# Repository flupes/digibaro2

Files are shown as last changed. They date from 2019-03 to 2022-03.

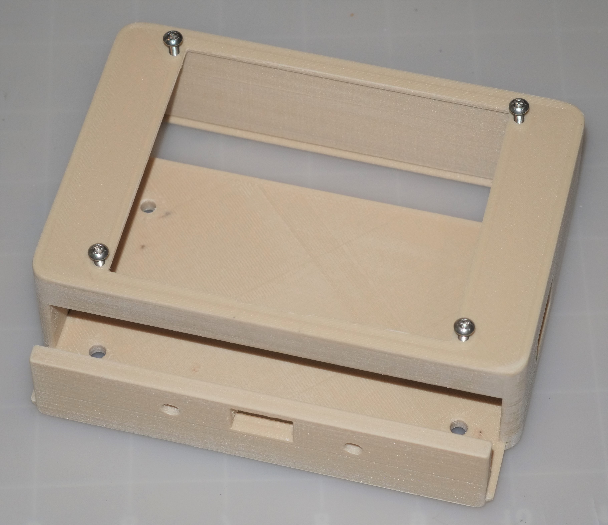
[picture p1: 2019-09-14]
brochure/D_mechanical/D4_enclosure.jpg

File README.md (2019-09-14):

# Digital Barograph v2 (with e-Paper display).

Status:
- all supporting custom libraries are now written and include tests
- main application functional
- schematic for board produced (one hole need fix)
- 3D [enclosure design with wooden plate](https://a360.co/2I1p0DZ) completed

Digibaro2 Photo

*Picture of the final barograph*

There is also a [complete user manual](./brochure/brochure.pdf) with a lot of cool
build pictures.
(The brochure has been written in French because I offered a Digibaro to
my father for his 80th birthday, but it should not prevent you to have a look
at it!)

## Goal

Develop an open source digital barograph that does not require an external power
source, has a very low power consumption, and works on a boat independantly of
any wifi/cell connection.

## Motivation

I still believe that the barometric pressure is an essential decision making
tool when sailing. Displaying a graph rather than writing down single values
provides an instant evaluation of the trend.

The main idea is that the beautifull conventional mechanical barograph are not
suited for marine use (not resistant to vibration) and require a weekly paper
change.

Classical Barograph

The paper-electronic barographs aleviate this problem, but I remember that ours
was constantly jamming.

Several electronic barograph already exist on the market, but they all require
an external source of power (and are pricey).

## Rationale

Today you can have an app that will siphon the data from a nearby weather
station and display the barometric pressure in any format using your brillant
smartphone screen. And this is even not really necessary since having data
connectivity would allow to also get a full detailed weather forecast, much more
accurate, and covering a wider area, than what you could analyze yourself.

Despite our ever more connected world, I am old fashioned and like to believe
that having systems not relying on data flowing wirelessly to your boat can be
useful. It turns out that the fundamental building block for such a project is
readily available: several extremely accurate digital pressure sensors can be
sourced at low price (you may already have one in your cellphone).

I also wanted not to rely on an external source of power. This is not so much to
avoid battery drain (the most basic solar panel would provide more than enough),
but to avoid having extra wiring.

The final concept is that you would be able to leave the barograph on your boat,
and when coming back after six months, you would be able to read the barometric
pressure of the last few days because the barograph would keep collecting data.
Of course, this is probably superfluous since after leaving your boat six
months, you probably have more than 5 days of work before taking the sea again
(hence you could turn on the barograph).

At any rate, being a style exercise or a real need, the goal is to develop an
extremly low power barograph that could sustain at least six months on a set of
typical AA alkaline batteries!

There are few major difference between this project an my previous (never
completed) digibaro v1:

| Digibaro v1 | Digibaro v2 |
|---|---|
| Target low cost | Cost is not the main priority |
| Classic UI with 5 buttons | Mimimalist UI (analog feel) |
| LCD screen | e-Paper display |
| Only stores 5 days of data  | Long term recording (>20years)|
| Typical "maker" approach | High reliability desired |

## Hardware selection

The [first version of my digibaro](https://github.com/flupes/digibaro/) was
based one BMP085 sensor, a momochrome graphic LCD and an Arduino Pro-Mini
(3.3V). This version use modernized components.

The micro-controller is a ARM Cortex M0+ (SAMD21) packaged by RocketScream. This
board was selected because it was specifically designed for low power
applications (no extra LEDs, efficient regulator, etc.), and it provides 2MB of
flash memory on board.

The pressure sensor is a BOSH BME280. It provides excellent accuracy plus a
humidity and temperature sensor on the chip. The BMP680 would provide an extra
Volatile Organic gas detector, but a the cost of an extra complexity in managing
the sensor.

The display is based on a 400x300 black and white e-Paper system packaged by
Waveshare. E-paper display would seem ideal for this type of low power
application. However, since the refresh rate is so slow (~4s for this particular
display), updating the display takes a significant amount energy. There is a
cutting-point between a LCD (that refresh very quickly and consume very low
power in standby) and an e-Paper display that depends on the number of refresh
per day. Still, for this application, the e-Paper provides a nice, more natural,
look.

## Reference products

[Bohlken BG1512](http://www.bohlken.net/bg/bg1512_en.htm)
- Require external power source
- 10mA without backlight
- Retired
- ~300 Euro

[Aquatech DBX2](https://www.digitalbarograph.com/)
- Require external power source
- 20mA @ 5V DC (160mA with LED backlight)
- Storm alarm
- Factory calibrated
- [DBX2 User Manual](https://www.digitalbarograph.com/pdfs/DBX2_MANUAL_V1W.pdf)  
- ~$500

[NASA Meteoman](https://www.nasamarine.com/product/meteoman/)
- Consumes 100mA (without backlight), require external source of power
- Pressure change graph
- [Meteoman screenshots and discussion](http://www.ybw.com/forums/showthread.php?452897-Calling-Weather-Experts-What-do-you-Need-in-a-Barograph)
- ~$200

[Raber Barograf](http://www.barograph.ch/Barograph_E/barograph.html)
- Paper recording :-)
- Swiss made ;-)
- One single C type battery for a year!
- Very cool, however we had a similar model that jammed quite often.  
- [Meteograf User Manual](http://www.barograph.ch/Downloads/BA_Meteograf_Englisch_2.4.pdf)  
- ~$900 without case

## Related projects

In May 2019, I just discovered this: [Arduino + BMP085 Barograph from PauloDevelo on Arbatus](https://www.arbutus.ecogium.fr/the-boat/electronic-equipment/barograph-arbutus/).

<!-- 
Code at: https://github.com/PauloDevelo/Barograph/blob/master/src/barograph.ino

This is similar to to what I started to develop with v1 of digibaro. However,
PauloDevelo chose a much simpler route: it is again powered from the boat
batteries (so not need for sleep mode), there is no RTC, no real concept of time
series, no user interface per say. This allowed him to complete the project
(unlike my digibaro v1). Congratulations! In addition, he created a nice wooden
enclosure.
-->

## Build

Currently digibaro2 is built using platformIO. This mainly constrains the
directory structure. Each test program show in the comments the command
to build it. The main application uses the platormio.ini definitions and
calls an extra script (version.py) to inject the git hash. This last part
is not directly portable to another build system.

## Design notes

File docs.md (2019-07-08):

## Platform

The code in this repo is specifically designed for an Arduino "zeroUSB"
compatible using a **ARM Cortex M0+**. The board used for my project is a
[Mini Ultra Pro v2](https://www.rocketscream.com/blog/docs-item/mini-ultra-pro-hookup-guide/)
from "Rocket Scream". The board was choosen because it has been designed for low
power application, and it already has a 2MB on-board flash. The Cortex M0 uses a
`SAMD21` which is a 32-bit microcontroller with 32KB or RAM. So there is very
little optimization to use types smaller than the native **word** `uint32_t` or
`int32_t`.

## Code organization

Most of the code resides in individuals libraries under `lib`. This allows for
much easier unit testing, at the cost of a lot of folders to deal with.

## General concepts

Class `BaroSample` holds information collected from the BME280 sensor, in a
slightly more compact form, using uint16_t rather than uint32_t. The class
also allows serialization and de-serialization to flash memory.

BaroSamples are written two flash using two classes:

  - `PermanentSamples` stores low frequency (typically hourly) samples, until
    the flash memory is full (~29 years of data!). These samples are not
    supposed to be deleted or written over.
  - `RotatingSamples` holds higher frequency samples (typically every 5
    minutes). This is a circular buffer, with samples being overwritten when the
    buffer is full. The length of this circular buffer ensure that the flash
    memory will not be subject to too many cycles.
    This class is supported by `RobustFlashIndexes` which maintains which is
    the last index of the circular buffer. The use of this separate circular
    buffer allows extra safety in maintaining the indexes because of the 
    redundancy and CRC offered by RobustFlashIndexes.

## Tests

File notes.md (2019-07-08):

Powershell tricks for the Linux guy
-----------------------------------

echo $PATH
$env:path -split ";"

which
(Get-Command cmd).Path

create new profile file
New-Item $profile -ItemType File -Force

test if path exist
Test-Path $profile

powershell editor
powershell_ise.exe $profile

create alias (only for session)
New-Item -Path Alias:python3 -Value C:\ProgramData\Anaconda3\python.exe

sloc count:
cloc --list-file=src-includes.lst --exclude-list-file=excluded.lst \
    --force-lang="C++",c --exclude-ext=csv

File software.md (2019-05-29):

# Digibaro Software Overview

All libraries used by digibaro2 are included with the repo, either as simple
directories (if the library is only relevant to digibaro), or as a git submodule
if the library has other application (this is the case for all the external
dependencies).

## Dependencies (External Libraries)

### Adafruit-GFX-Library

Used for all the drawing primitives and the canvas on which to draw.

### epd42

Waveshare code to drive their 4.2in black and white display. The drawing is done
on the Adafruit canvas, that is then pushed to the display.

### BME280_driver

This is the low level code provided by BOSH to interface with the BME280. Added
to this code is also a thin wrapper class to use the sensor Arduino style.

### FastCRC

Provides CRC functionalities

### RTCZero

SAMD21 internal RTC and power management.

### SPIMemory

Access the on-board flash.

## Internal Code and Libraries

### BaroUtils

Some utilities used by most of the code, like a printf dependent on the USB
avaibility.

### BaroSample
Management of data collected from the BME280 sensor (timestamp, serializing,
packing, etc.).

### PermanentSamples

Stores (and read) samples permanently in flash (just a linear succession of
samples).

### RobustFlashIndexes

Indexes on flash with redundancy and CRC checks.

### RotatingSamples

Rotating buffer on of sample on flash. Relies on RobustFlashIndexes.

### DisplaySamples

Creates RAM based timeseries of samples from flash.

### GraphSamples

Draw a graph from the DisplaySamples

### Labels

Compute nice axis label (from Numerical Recipes)

### RTClib

Manage the external DS3231 RTC (custom fork)

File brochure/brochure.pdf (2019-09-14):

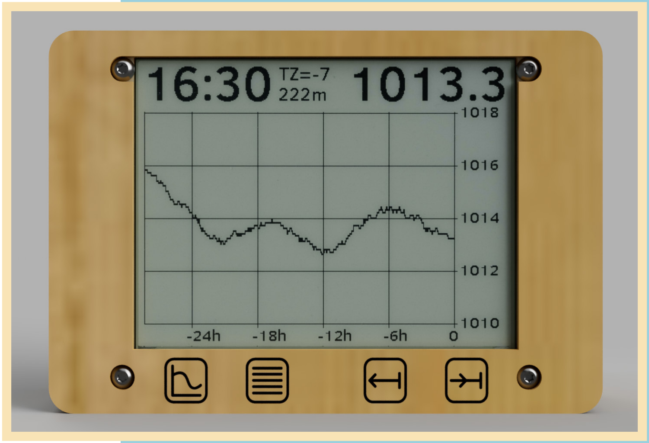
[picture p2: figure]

# Digibaro

# Barographe Electronique

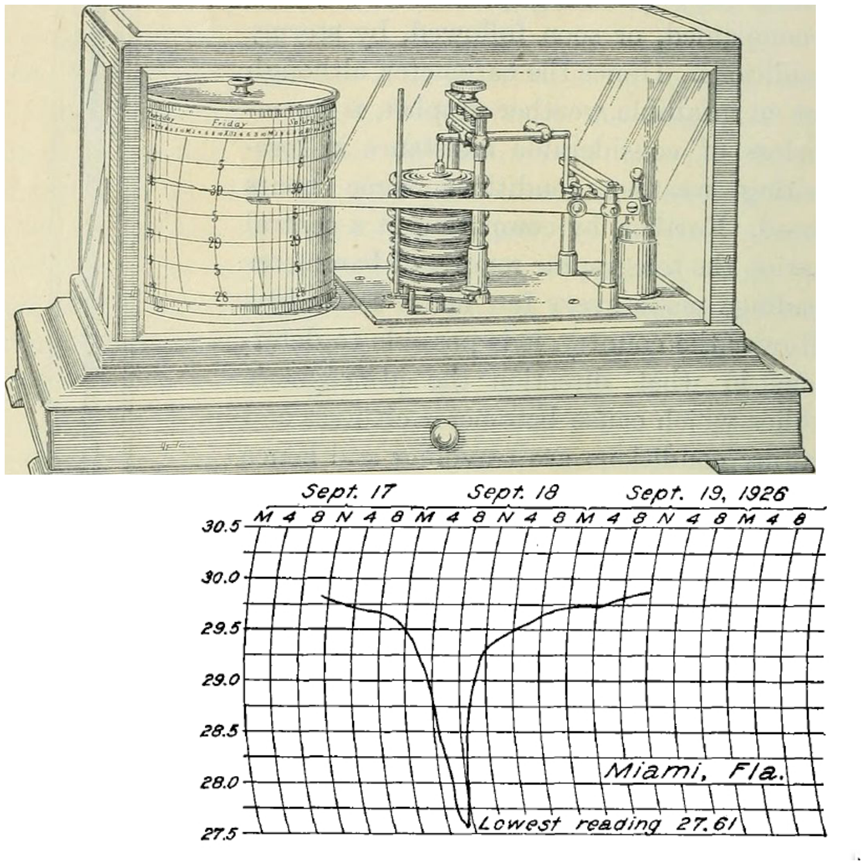
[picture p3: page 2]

Un nouveau concept de barographe en 2019?
Aujourd’hui, il est possible de siphonner en un instant les données de la station météo la plus proche sur son smartphone, ou d’obtenir les prévisions météo sur plusieurs jours pour n’importe quelle zone avec un précision incroyable. Cependant, si vous êtes un peu vieux jeu, décidez de naviguer dans une zone où la transmission de donnée est difficile, ou tout simplement êtes intéressé par les conditions locales, un baromètre reste un outil indispensable. Et un barographe, qui permet en un clin d’oeil d’évaluer la tendance, fournit un confort supplémentaire.
Les barographes mécaniques ne sont pas adaptés aux conditions sur un voilier. Il existe plusieurs barographes électroniques sur le marché, mais tous nécessitent d’être reliés à une source de courant externe.
Le “Digibaro” est optimisé pour fonctionner de manière continue avec 3 petites piles rondes (AA) pour plus de six mois. De plus, son écran e-papier combiné avec une interface composée uniquement de 2 interrupteurs à bascule offre un design “analogique” unique d’un usage extrêmement simple.
L’ensemble du projet Digibaro est Open-Source, n’importe qui peut donc en construire une version et la modifier si besoin. Cela permet aussi de réparer facilement l’appareil puisque toutes les informations sont disponibles.
Voici le premier prototype du Digibaro, spécialement construit pour fêter les 80 ans de Papi Bateau!

# Introduction

# Manuel d’utilisation

Deux interrupteurs à bascule permettent de sélectionner un des quatre modes d’affichage. Le Digibaro mesure la pression chaque minute, mais ne met à jour l’écran que toute les 5 minutes. Le reste du temps, le Digibaro reste en sommeil profond, ne consommant que 0.12mW (environ 5000 fois moins qu’un smartphone avec écran éteint)! Chaque mouvement d’un interrupteur réveille le Digibaro et rafraîchit l’écran. Il faut environ 5 secondes pour rafraîchir ce type de e-papier, donc

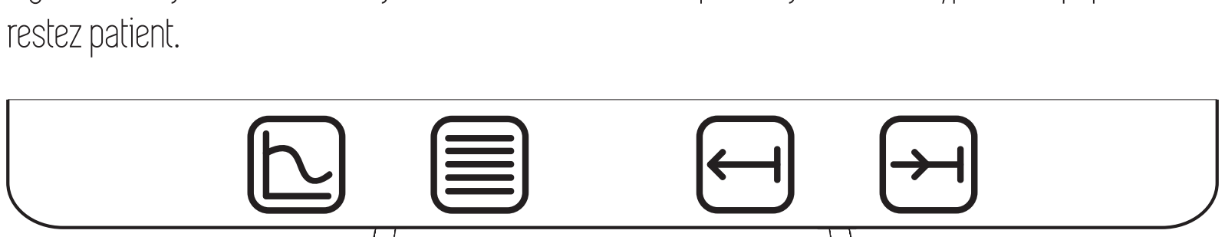
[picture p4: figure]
restez patient.

Affichage
Mode Texte

Affichage
Graphique | Periode ~1 jour
Periode ~5 jours | (détails)
(large)
» Interrupteur principal: accessible par une encoche en dessous du Digibaro, se trouve un interrupteur à glisser. Pousser vers le centre de l’appareil pour allumer, ou vers la gauche pour éteindre. » Changement des batteries principales: simplement enlever les trois piles AA (avec délicatesse, utiliser un outil pour aider à les sortir), et remplacer avec des nouvelles.
» Pile de sauvegarde de l’horloge: tous les trois ans il faut changer la pile bouton. Suivre la procédure en dernière page afin de ne pas perdre l’heure.

# Configuration des paramètres

La zone horaire ainsi que l’altidude sont configurés en utilisant les 6 boutons à glisser (DST=Daylight Saving Time=Heure d’été).

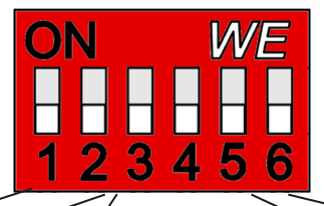
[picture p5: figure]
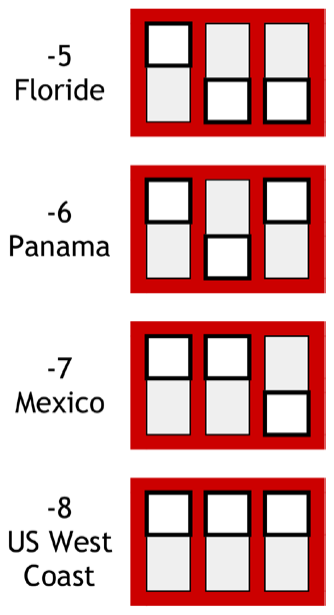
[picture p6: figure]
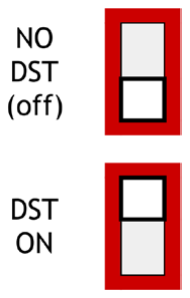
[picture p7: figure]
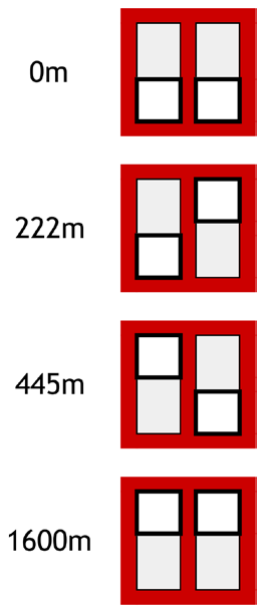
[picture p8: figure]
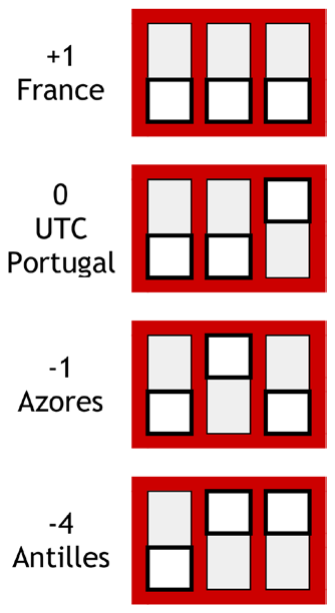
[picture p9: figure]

Il est fortement conseillé d’arrêter le Digibaro en actionnant l’interrupteur principal (glissé vers la gauche=OFF) avant de voyager. Une fois sur place, configurez d’abord l’altitude appropriée, puis mettez en fonction le Digibaro.

1 2 | 3 4 5 | 3 4 5 | 6

# Electronique

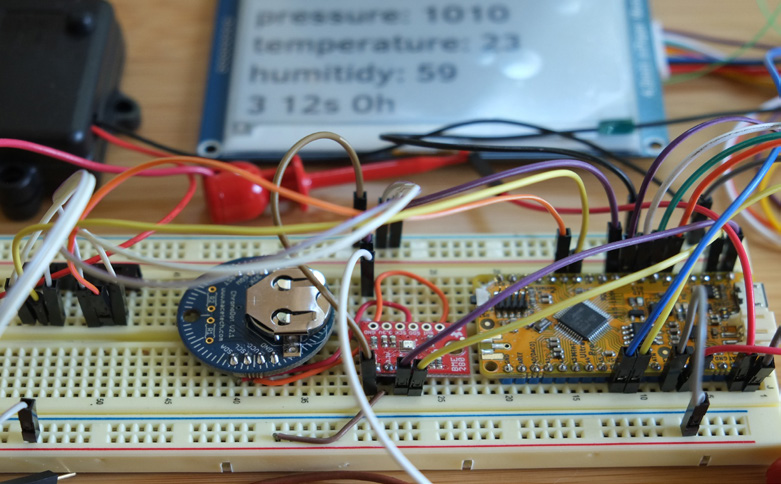
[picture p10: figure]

Le Digibaro est constitué des plusieurs composants électroniques disponibles sur le marché. Les composants ont été sélectionnés pour répondre à un cahier des charges avec le but premier de minimiser la consommation électrique. Un circuit imprimé (circuit violet) spécialement conçu pour ce projet permet de connecter tous ces composants:
» Le capteur de pression, température et humidité, le BME280 déjà placé sur une carte assemblée par Sparkfun (circuit rouge)
» Une montre ultra-précise pour conserver le temps, la DS3231 montée sur la carte ChronoDot (circuit bleu).
» Le microcontrôlleur 32 bits reliant tous les périphériques et senseurs est basé sur un SAMD21 assemblé sur une carte de Rocket-Scream (circuit jaune)
» L’écran “papier électronique” est assemblé

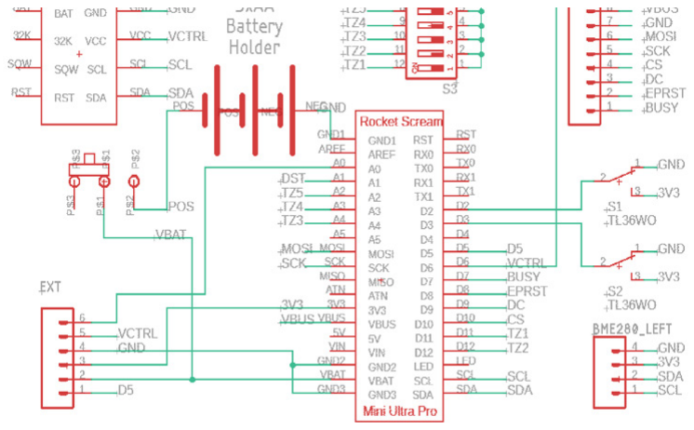
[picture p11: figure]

# Du concept à la réalisation

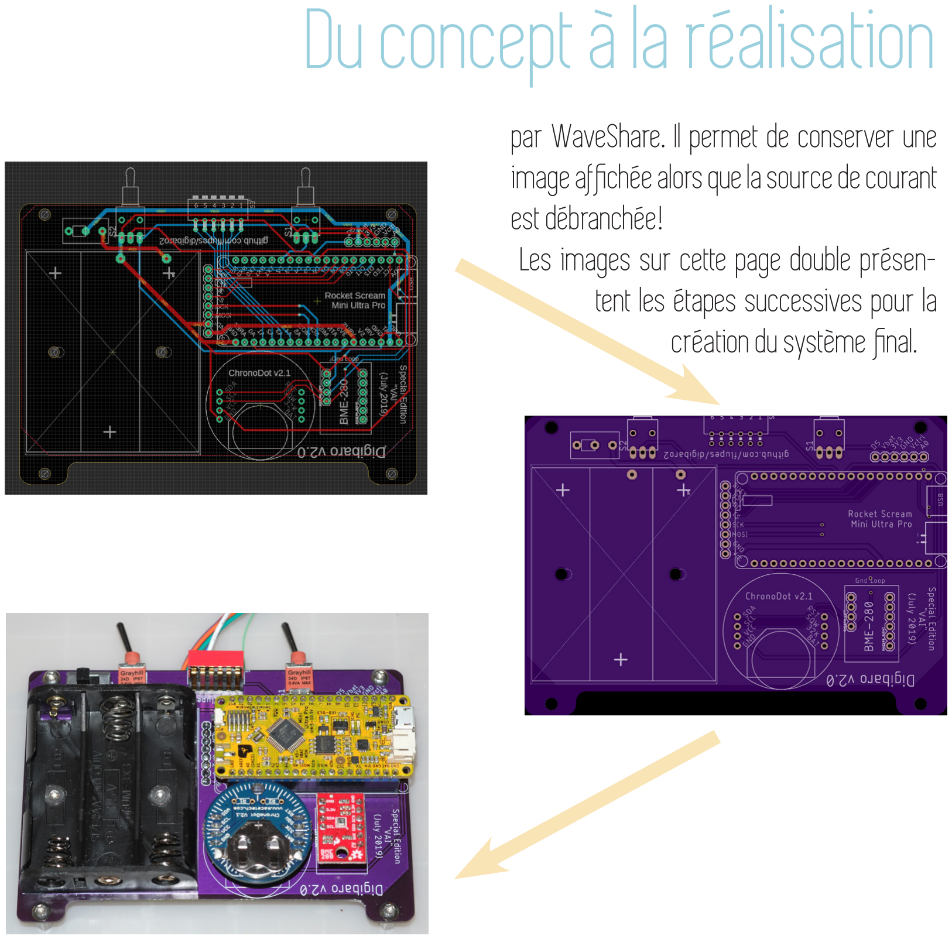
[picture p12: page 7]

par WaveShare. Il permet de conserver une image affichée alors que la source de courant est débranchée!
Les images sur cette page double présentent les étapes successives pour la création du système final.

# Logiciel

Le logiciel pour Digibaro s’occupe de lire les informations des sensors et interrupteurs, de dessiner les graphiques et information textuelles. Chaque mesure météo est associée avec une date et heure précise, puis compressée afin de pouvoir stocker environ 25 ans de données horaires sur les 2MB (moins qu’une seule photo de smartphone) de mémoire permanente disponible!

Le système est conçu pour être résilient à toute interruption par un stockage fiable des informations détaillées des cinq derniers jours. Une attention toute particulière a été dédiée

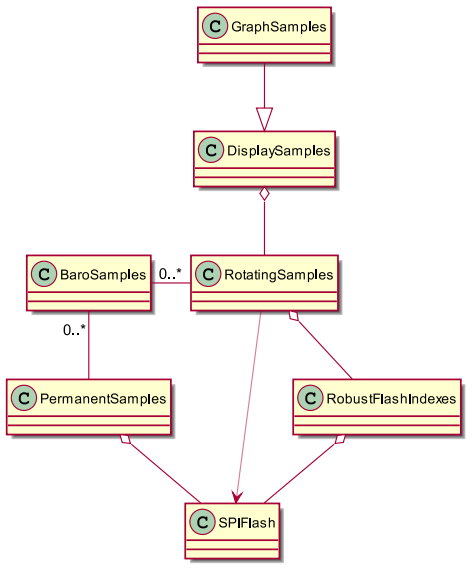
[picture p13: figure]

pour permettre de configurer le microcontrôleur de manière à consommer de moins de courant possible en mode sommeil profond tout en restant à l’écoute du réveil de l’horloge ou des interrupteurs.

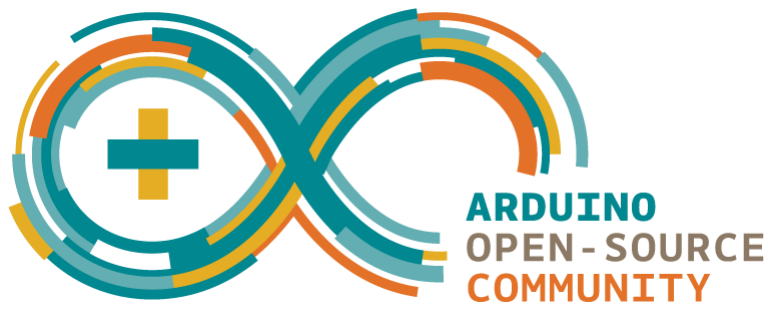
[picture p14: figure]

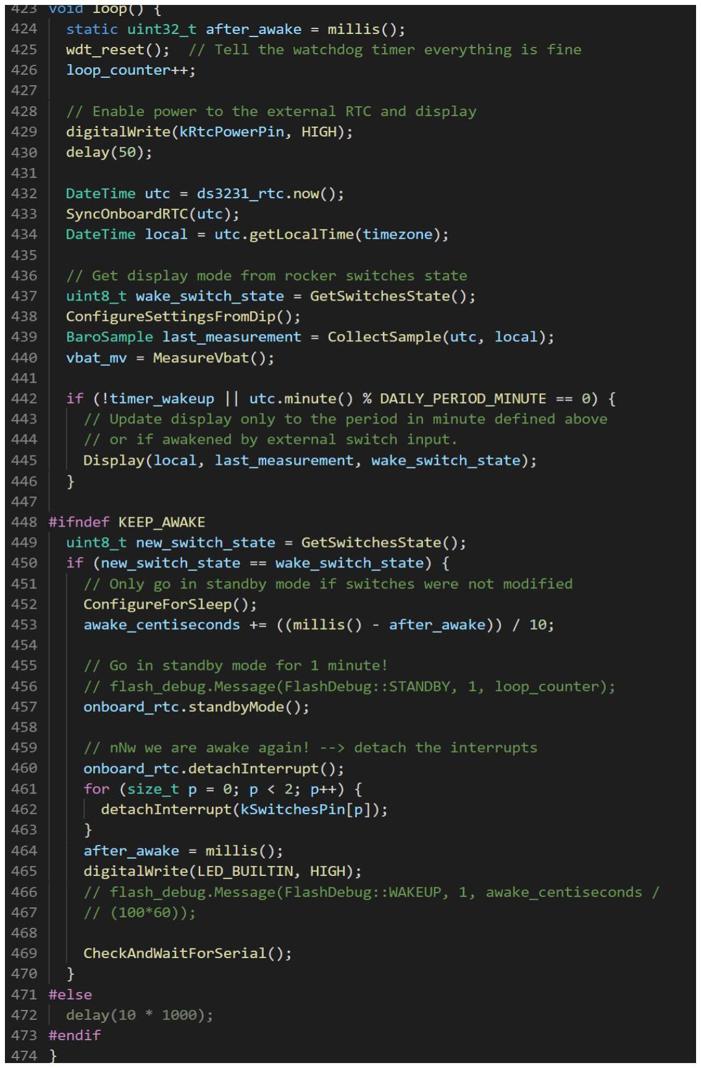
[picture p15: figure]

Probablement l’aspect du Digibaro qui a demandé le plus d’effort, le software nécessaire pour Digibaro, compte 5000 lignes de code (~100 fois l’extrait ci-joint). C’est donc un petit projet qui repose toutefois sur de nombreuses libraries totalisant environ 50’000 lignes de code. Par exemple, les routines de dessin bas-niveau sont développées par Adafruit. Ces librairies sont aussi Open-Source, ce qui permet, si nécessaire, de les adapter pour ce projet.
La plateforme logicielle Arduino, permettant de développer des applications pour le type de microcontrôleur utilisé, facilite grandement de type de projet.

# Code

# Boitier

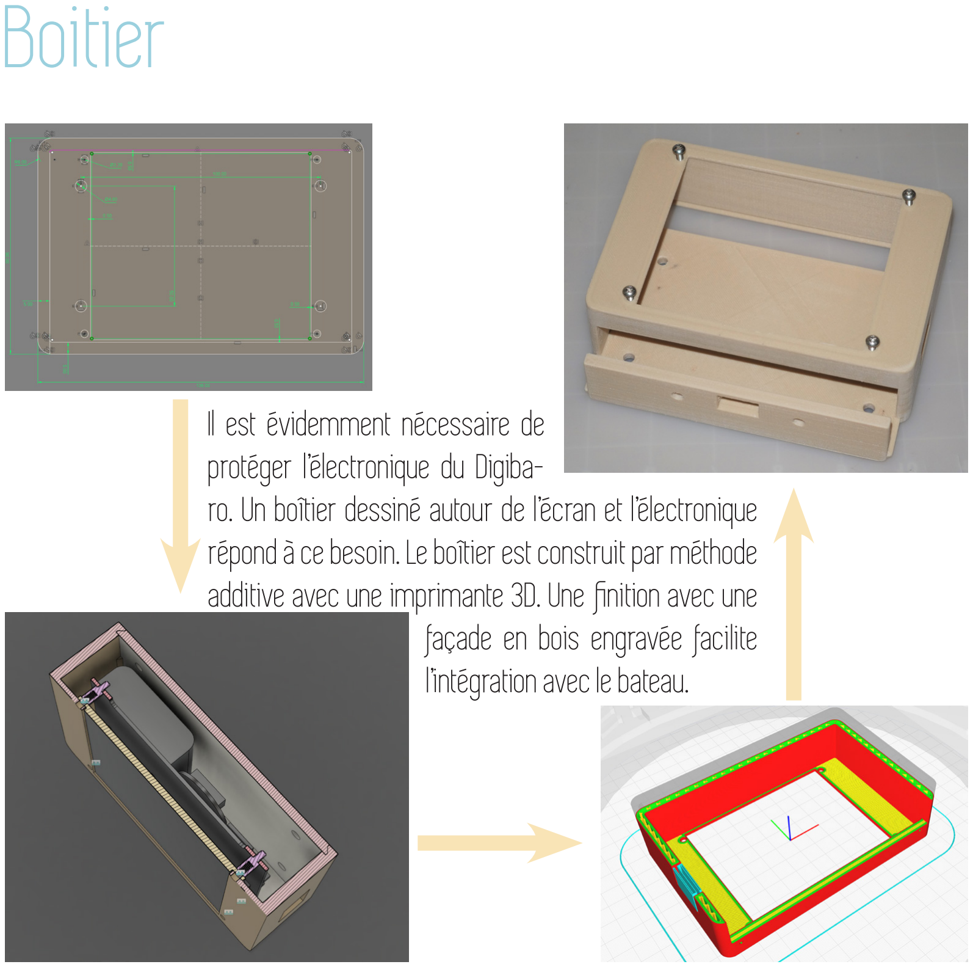
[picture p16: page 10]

Il est évidemment nécessaire de
protéger l’électronique du Digibaro. Un boîtier dessiné autour de l’écran et l’électronique répond à ce besoin. Le boîtier est construit par méthode additive avec une imprimante 3D. Une finition avec une façade en bois engravée facilite l’intégration avec le bateau.

# Spécifications

Précision barométrique absolue | ± 1 mbar
Précision barométrique relative | ± 0.1 mbar
Stabilité de l’horloge | ± 2 ppm ~ 1 min / année max.
Résolution d’écran | 400 x 300 pixels
Précision température | ± 1 ° C
Precision humidité | ± 3%
Consommation moyenne | > 6 mois avec 3 x AA (à valider ;-) )

Changement de la pile de sauvegarde pour l’horloge:
1. Ouvrir le boitier
2. Préparer la pile bouton de rechange
3. Eteindre l’appareil
4. Allumer l’appareil, et dés que l’écran affiche le message de bienvenue, retirer la pile bouton
5. Insérer la nouvelle pile moins de 20s après allumage

## Open Source Hardware:

Les companies référencés dans cette brochure portent des noms sympas, mais en plus, elles contribuent activement à la communauté Open Source (hardware et software). Ceci au bénéfice des “makers”, et aussi de nombreuse autre organizations (comme la NASA). Elles méritent donc toutes une visite:
» Adafruit | https://www.adafruit.com
» Arduino | https://www.arduino.cc
» ChronoDot | http://macetech.com/store/index.php?main_page=product_info&products_id=8
» RocketScream | https://www.rocketscream.com
» Sparkfun | https://www.sparkfun.com/
» WaveShare | https://www.waveshare.com

## Digibaro sur le web:

https://github.com/flupes/digibaro2

Digibaro a été conçu et assemblé en Californie par Lorenzo Dessin icônes Digibaro et thème brochure par Kenzo

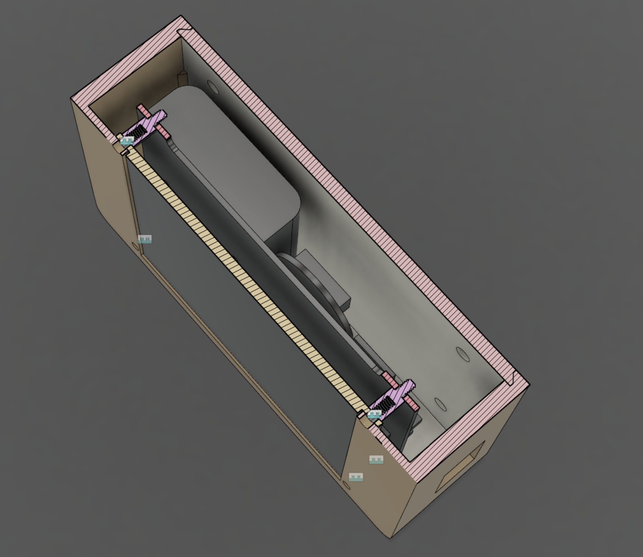
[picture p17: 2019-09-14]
brochure/D_mechanical/D2_CAD.png

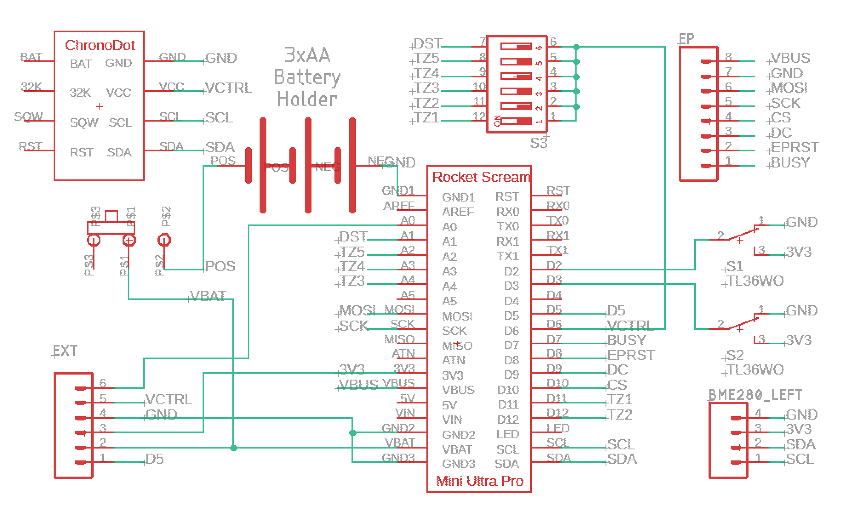
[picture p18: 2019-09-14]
brochure/B_electro/B2_schematics.png

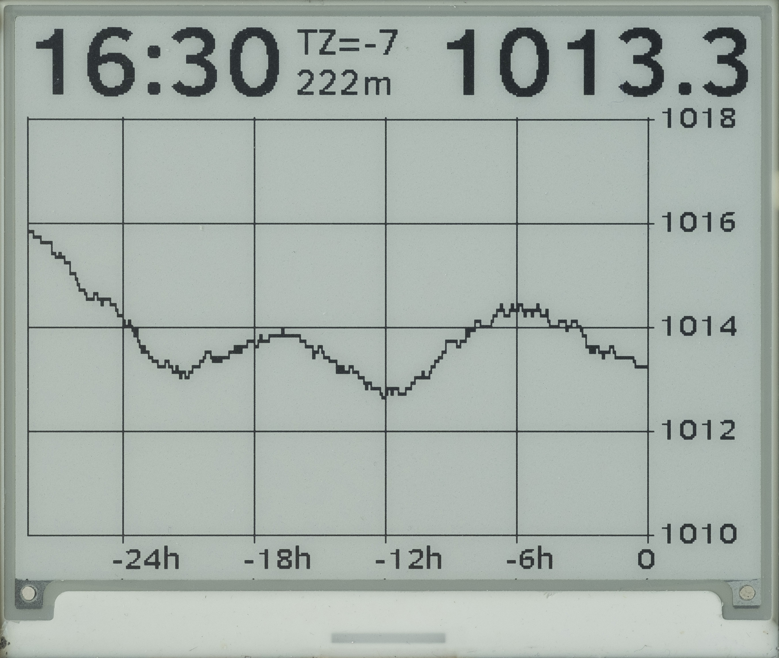
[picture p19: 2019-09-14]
brochure/epaper_with-graph.jpg

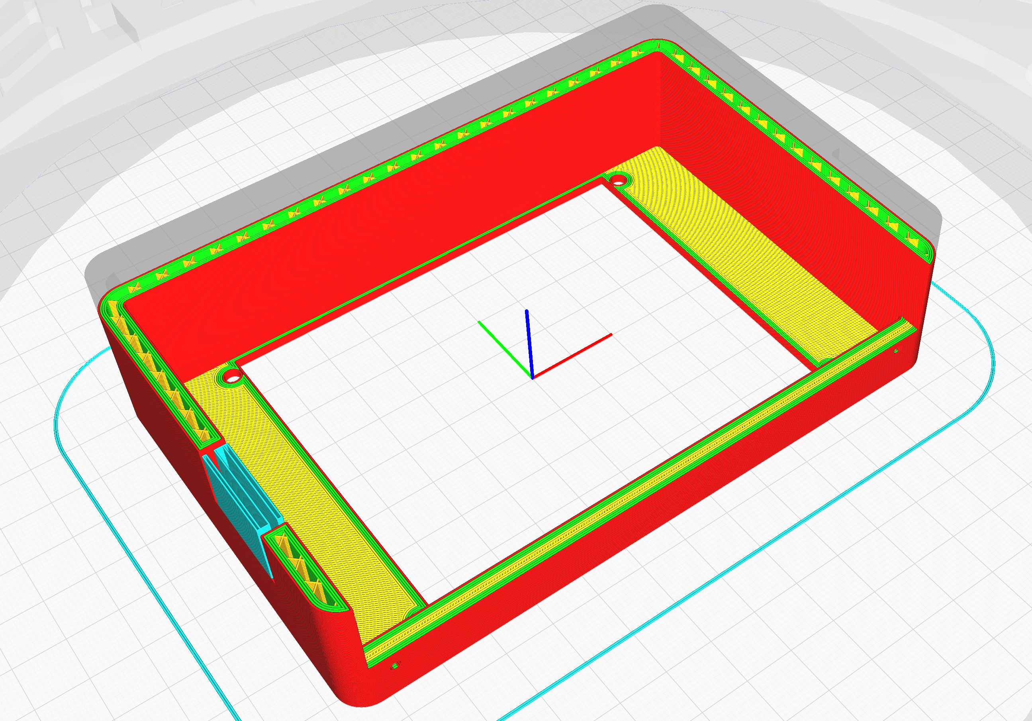
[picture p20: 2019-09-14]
brochure/D_mechanical/D3_sliced.png

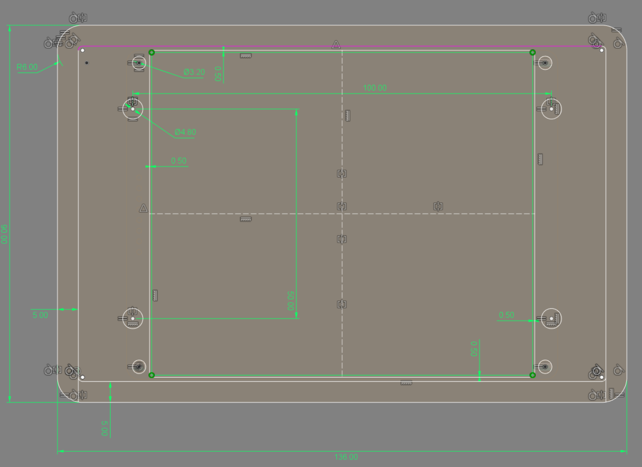
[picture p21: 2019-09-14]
brochure/D_mechanical/D1_sketch.png

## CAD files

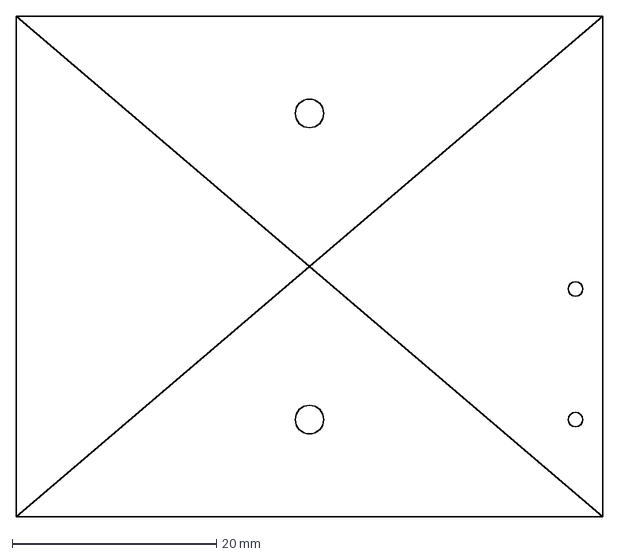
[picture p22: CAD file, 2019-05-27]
hw/battery_holder.dxf
57.5 x 49.0 mm

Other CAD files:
brochure/icons.dwg
brochure/digibaro v52.dwg

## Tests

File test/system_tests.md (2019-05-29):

# System level tests

This directory contains a set of tests that require multiple libraries at once,
or some tests or utilities not specific to a library in particular.

## DipSwitchSleep

Check that the DIP switch wiring and board configuration does not consume
current in sleep mode.

## ErasePermanentSamples

Simply wipes out the existing "permanent" samples stored in flash, using the
default memory map.

## ExtInterrupt

Shows how a SPDT switch can be wired to consume not current and wake up the
SAMD21 from sleep using an interrupt.

## PackedBitField

Verifies how the compiler packs data structures and bit fields on the 32 bits
SAMD21 processor.

## ReadFlashSamples

Just reads all the "permanent" samples from flash and print them out.

## RecordData

Badly named, obsolete test. Was showing how to reliably read from flash using
a reduncdancy of 2 plus a CRC.

## SleepTest

Demonstrate how to put to sleep the SAMD21 connected to all its devices (RTC,
Display and BME280). The measurements show consumption of ~25uA if all the pins
are correctly configured and all the un-necessary devices disconnected.

## TestBme280Sensor

Simple test of the BME280_Driver library and associated class.

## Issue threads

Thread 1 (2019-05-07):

SPIFlash does not wake up from sleep without removing power

flupes, 2019-05-07:
If the flash is put in sleep mode, a begin() after rebooting blocks unless power is completely removed from the board.

The lock occurs because !_notBusy never returns:

```
bool SPIFlash::_getJedecId(void) {
   if(!_notBusy()) {
     return false;
   }
```

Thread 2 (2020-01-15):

Graph does not scale properly

flupes, 2020-01-15:
If using FIXED_SCALE (lib/GraphSamples/src/graph_samples.cpp), the graph does not extend its bounds if the pressure is too high.
This is a likely a side effect of the quickly implemented FIXED_SCALE mode.
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

jonathanfave, 2023-02-13:
Hello,

I am interested in your barometer project. I currently have the right components in my possession and I would like to have more information on your code deposited on the github, is it possible to exchange together on this subject?

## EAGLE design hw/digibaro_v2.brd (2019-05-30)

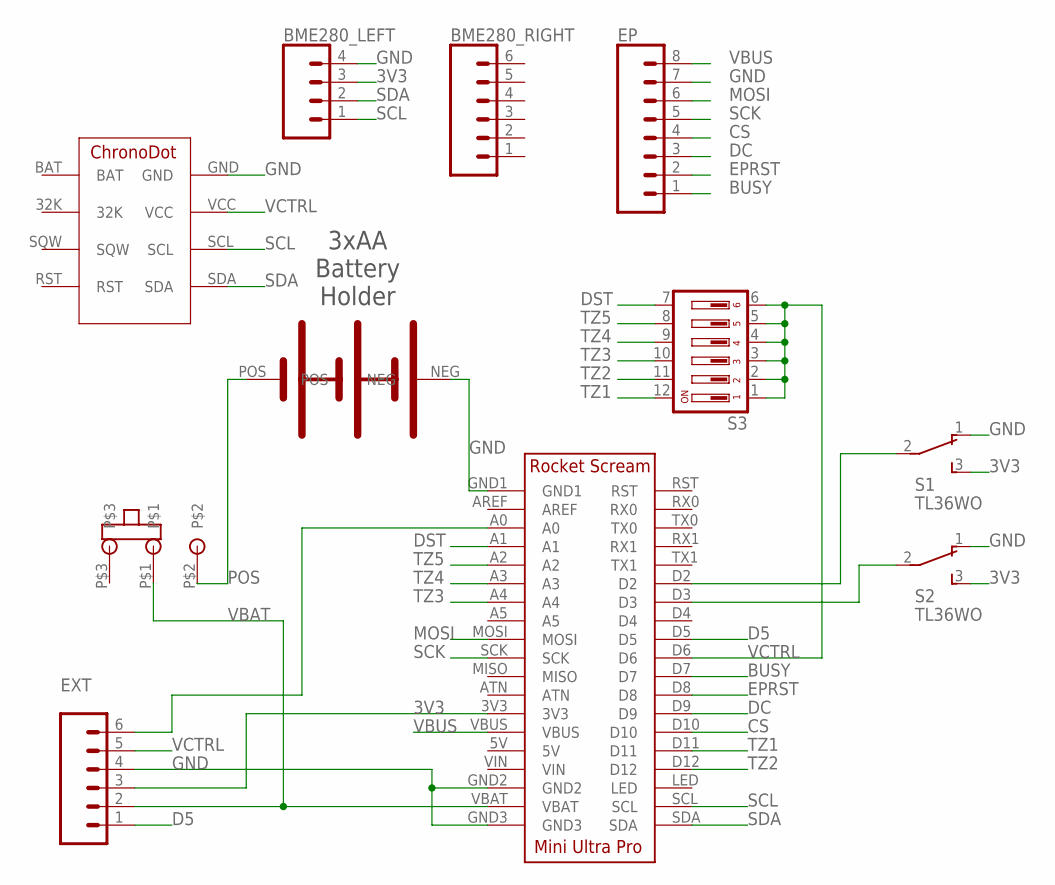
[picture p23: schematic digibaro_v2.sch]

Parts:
BME280_LEFT: CONN_04; 1X04
BME280_RIGHT: CONN_06SILK_FEMALE_PTH; 1X06
EP: CONN_08"; 1X08
EXT: CONN_06SILK_FEMALE_PTH; 1X06
S1, S2: TL36WO; TL3XWO
S3: DA06; DA-06
U$1: BATTERY-HOLDER_3AA
U$2: SLIDE-SWITCHNKKMINIATURE; MS12ANG03
U$3: ULTRA-MINI-PRO; ULTRA-MINI-PRO_RECEIVER
U$4: CHRONODOT; CHRONODOT_RECEIVER

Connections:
3V3: BME280_LEFT.3, EXT.3, S1.3 (S), S2.3 (S), U$3.3V3
A0: EXT.6, U$3.A0
BUSY: EP.1, U$3.D7
CS: EP.4, U$3.D10
D5: EXT.1, U$3.D5
DC: EP.3, U$3.D9
DST: S3.7, U$3.A1
EPRST: EP.2, U$3.D8
GND: BME280_LEFT.4, EP.7, EXT.4, S1.1 (O), S2.1 (O), U$1.NEG, U$3.GND1, U$3.GND2, U$3.GND3, U$4.GND
MOSI: EP.6, U$3.MOSI
unnamed: S1.2, U$3.D2
unnamed: S2.2, U$3.D3
POS: U$1.POS, U$2.P$2
SCK: EP.5, U$3.SCK
SCL: BME280_LEFT.1, U$3.SCL, U$4.SCL
SDA: BME280_LEFT.2, U$3.SDA, U$4.SDA
TZ1: S3.12, U$3.D11
TZ2: S3.11, U$3.D12
TZ3: S3.10, U$3.A4
TZ4: S3.9, U$3.A3
TZ5: S3.8, U$3.A2
VBAT: EXT.2, U$2.P$1, U$3.VBAT
VBUS: EP.8, U$3.VBUS
VCTRL: EXT.5, S3.1, S3.2, S3.3, S3.4, S3.5, S3.6, U$3.D6, U$4.VCC

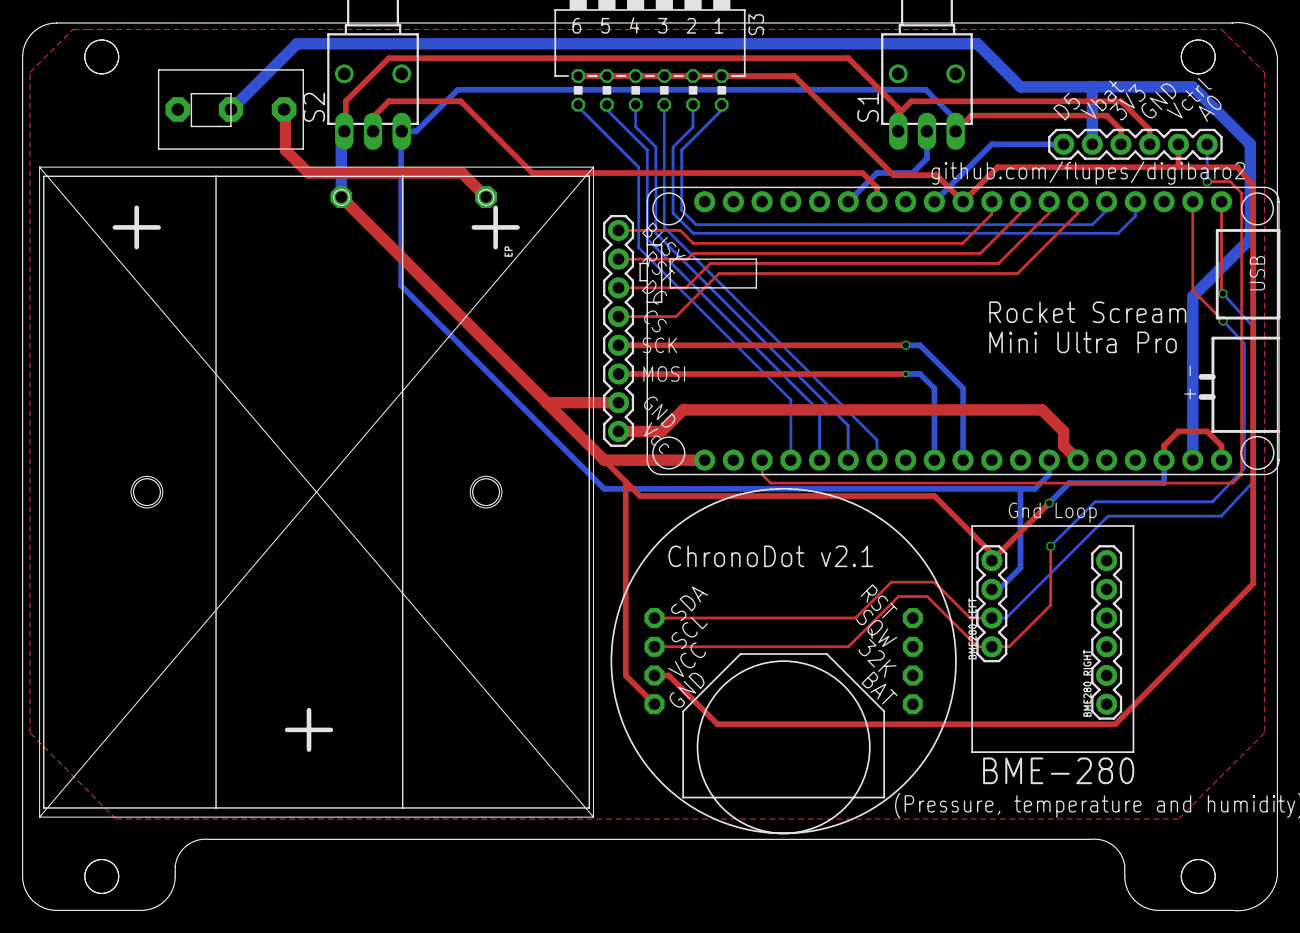
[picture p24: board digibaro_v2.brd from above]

Board: 2 copper layers, 111.0 x 78.6 mm, 11 parts (0 on the bottom side), 24 nets.

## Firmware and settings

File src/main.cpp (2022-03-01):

// monitor with:
// pio device monitor --port COM5 --baud 115200

#include <avr/dtostrf.h>

#include "Adafruit_GFX.h"
#include "Fonts/ClearSans-Medium-12pt7b.h"
#include "Fonts/ClearSans-Medium-16pt7b.h"
#include "Fonts/ClearSans-Medium-18pt7b.h"
#include "Fonts/ClearSans-Medium-32pt7b.h"

#include "baro_sample.h"
#include "digibaro.h"
#include "display_samples.h"
#include "graph_samples.h"
#include "print_utils.h"
#include "vai_silouhette.h"
#include "watchdog_timer.h"

// #define KEEP_AWAKE

// #define STRESS_TEST

// canvas to draw on
GFXcanvas1 *canvas;

// Permanent samples written to flash
PermanentSamples permanent_samples(spi_flash);

// Rotating buffer of samples
RotatingSamples rotating_samples(spi_flash);

#ifndef STRESS_TEST
#define DAILY_PERIOD_MINUTE 5
#define WEEKLY_PERIOD_MINUTE 20
#else
#define DAILY_PERIOD_MINUTE 2
#define WEEKLY_PERIOD_MINUTE 10
#endif

GraphSamples daily_buffer(DAILY_PERIOD_MINUTE * 60);
GraphSamples weekly_buffer(WEEKLY_PERIOD_MINUTE * 60);

uint32_t uptime_seconds = 0;
uint32_t awake_centiseconds = 0;
uint32_t loop_counter = 0;

uint32_t samples_on_flash = 0;
uint32_t vbat_mv = 0;
int16_t current_line = 0;
int16_t altitude = 0;
int8_t timezone = 0;

enum DisplayMode : uint8_t { STATS = 0, INFO = 1, DAILY = 2, WEEKLY = 3 };

uint8_t display_rotation = 0;

extern "C" char *sbrk(int i);

int FreeRam() {
  char stack_dummy = 0;
  return &stack_dummy - sbrk(0);
}

void ConfigureSettingsFromDip() {
  uint8_t dip_switches_state = GetDipState();
  DEBUG("DIP state = ", dip_switches_state);
  uint8_t alt_code = dip_switches_state >> 4;
  uint8_t tz_code = (0x0F & dip_switches_state) >> 1;
  uint8_t dst_mode = 0x01 & dip_switches_state;
  DEBUG("alt_code", alt_code);
  DEBUG("tz_code", tz_code);
  DEBUG("dst_mode", dst_mode);
  altitude = kAltitudes_options[alt_code];
  timezone = kTimezones_offset[tz_code] + dst_mode;
}

void SyncOnboardRTC(DateTime &utc) {
  if (loop_counter % 60 == 0) {
    // re-sync the onboard RTC every hour
    onboard_rtc.setTime(utc.hour(), utc.minute(), utc.second());
    onboard_rtc.setDate(utc.day(), utc.month(), uint8_t(utc.year() - 2000));
  }
}

void CheckAndWaitForSerial() {
  if (serial_attached) {
    USBDevice.init();
    USBDevice.attach();
    uint8_t count = 0;
    while (!Serial && count < 9) {
      delay(1000);
      count++;
    }
  }
}

void setup() {
  Serial.begin(115200);

#ifdef SERIAL_DEBUG
  uint8_t count = 0;
  while (!Serial && count < 12) {
    delay(1000);
    count++;
  }
  if (!Serial) {
    USBDevice.detach();
    serial_attached = false;
  }
#endif

  PRINTLN("Digibaro Starting...");

  ConfigureDevices();
  ConfigureSettingsFromDip();
  flash_debug.Message(FlashDebug::INIT, 0, 0);

  vbat_mv = MeasureVbat();

  ep42_display.ClearFrame();
  PRINT("Free RAM before Canvas allocation: ");
  PRINTLN(FreeRam());
  canvas = new GFXcanvas1(400, 300);
  PRINT("Free RAM after Canvas allocation: ");
  PRINTLN(FreeRam());
  uint8_t switch_state = GetSwitchesState();
  if (switch_state == 1) {
    // two switches pointing inside
    display_rotation = 2;
  }
  canvas->setRotation(display_rotation);

#ifndef KEEP_AWAKE

  canvas->fillScreen(0);
  canvas->drawBitmap(0, 0, vai_silouhette.data, vai_silouhette.width,
                     vai_silouhette.height, 1);
  canvas->setTextColor(0);
  canvas->setTextSize(1);
  canvas->setTextWrap(false);
  canvas->setFont(&ClearSans_Medium18pt7b);
  canvas->setCursor(185, 115);
  canvas->print("VAI");
  canvas->setCursor(185, 180);
  canvas->print("DigiBaro");
  ep42_display.DisplayFrame(canvas->getBuffer());

#ifdef SERIAL_DEBUG
  // crucial delay to let us chance to reflash!
  delay(5 * 1000);
#endif
#endif

#ifndef SERIAL_DEBUG
  uint8_t count = 0;
  while (!Serial && count < 20) {
    delay(1000);
    count++;
  }
  if (!Serial) {
    USBDevice.detach();
    serial_attached = false;
  }
#endif

  uint32_t last_index = rotating_samples.begin();
  PRINT("last rotating sample index = ");
  PRINTLN(last_index);

  PRINT("Permanent sample start addr = ");
  PRINTLN(kPermanentSamplesAddrStart);
  samples_on_flash = permanent_samples.begin();
  PRINT("Permanent sample retuned # = ");
  PRINTLN(samples_on_flash);

  // Initialized the buffers
  daily_buffer.Fill(rotating_samples, boot_utc.unixtime());
  weekly_buffer.Fill(rotating_samples, boot_utc.unixtime());

  // Configure the watchdog to 130s (two full cycles)
  wdt_configure(11);
}

BaroSample CollectSample(DateTime &dt, DateTime &local) {
  bme.PerformMeasurement();

  BaroSample sample(dt.unixtime(), bme.GetPressure() / 100,
                    bme.GetTemperature(), bme.GetHumidity() / 10, altitude,
                    timezone);

  if (Serial) {
    char buffer[56];
    local.toString(buffer);
    Serial.print("collect_sample at time = ");
    Serial.print(buffer);
    Serial.print(" : press = ");
    Serial.print(bme.GetPressure());
    Serial.print("  | temp = ");
    Serial.print(bme.GetTemperature());
    Serial.print("  | humi = ");
    Serial.print(bme.GetHumidity());
    Serial.println();
    Serial.print("--> sample created at elevation = ");
    Serial.print(altitude);
    Serial.print(" with seconds = ");
    Serial.print(sample.GetTimestamp());
    Serial.print(" : press = ");
    Serial.print(sample.PressureMilliBar());
    Serial.print(" | temp = ");
    Serial.print(sample.TemperatureDegCelcius());
    Serial.print(" | humi = ");
    Serial.print(sample.HumidityPercent());
    Serial.println();
  }

  if (dt.minute() % DAILY_PERIOD_MINUTE == 0) {
    rotating_samples.AddSample(sample);
  }
  if (dt.minute() == 0) {
    samples_on_flash = permanent_samples.AddSample(sample);
    flash_debug.Message(FlashDebug::STEP, 11, awake_centiseconds / (100 * 60));
  }
  return sample;
}

void DisplayLine(const char *buffer, int16_t spacing, int16_t x_offset = 2) {
  current_line += spacing;
  canvas->setCursor(x_offset, current_line);
  canvas->print(buffer);
}

void DisplayStats(DateTime &local, BaroSample &current) {
  char buffer[32];

  const size_t kPeriodHours = 3;
  const size_t kNbSamples = 11;
  DisplaySamples pressure_3h(kPeriodHours * 3600, kNbSamples);
  DisplaySamples temp_3h(kPeriodHours * 3600, kNbSamples);

  BaroSample last =
      rotating_samples.GetSampleAtIndex(rotating_samples.GetLastSampleIndex());

  last.PrettyPrint();
  pressure_3h.Fill(rotating_samples, last.GetTimestamp());
  pressure_3h.Print();
  temp_3h.Fill(rotating_samples, last.GetTimestamp(), TEMPERATURE);
  temp_3h.Print();

  canvas->setFont(&ClearSans_Medium18pt7b);
  current_line = 0;

  sprintf(buffer, "%04d-%02d-%02d %02d:%02d UTC%+d", local.year(),
          local.month(), local.day(), local.hour(), local.minute(), timezone);
  DisplayLine(buffer, 20, 16);

  char pressure_str[8];
  char temperature_str[8];
  char humidity_str[8];
  dtostrf(last.PressureMilliBar(), 5, 1, pressure_str);
  dtostrf(last.TemperatureDegCelcius(), 4, 1, temperature_str);
  dtostrf(last.HumidityPercent(), 4, 1, humidity_str);
  sprintf(buffer, "%s mb | %s C | %s%%", pressure_str, temperature_str,
          humidity_str);
  DisplayLine(buffer, 26);

  canvas->setFont(&ClearSans_Medium16pt7b);
  current_line += 6;

  char delta_str[8];
  // There is a bug: the first sample of the serie is invalid!
  // So: 1) the serie should be 1 element longer and 2) we want one extra
  // element for the first delta --> serie length = 9 + 2 !
  int16_t last_pressure = pressure_3h.Data(1);
  int16_t hours = -(int16_t)kPeriodHours * ((int16_t)kNbSamples - 3);
  for (size_t i = 2; i < kNbSamples; i++) {
    int16_t pressure = pressure_3h.Data(i);
    if (pressure == INT16_MIN) {
      sprintf(pressure_str, "----");
    } else {
      dtostrf((float)pressure / 10.0, 5, 1, pressure_str);
    }
    if (last_pressure == INT16_MIN || pressure == INT16_MIN) {
      sprintf(delta_str, "+#.#");
    } else {
      float delta = (float)(pressure - last_pressure) / 10.0;
      if (delta < 0) {
        delta_str[0] = '-';
        dtostrf(-delta, 3, 1, delta_str + 1);
      } else {
        delta_str[0] = '+';
        dtostrf(delta, 3, 1, delta_str + 1);
      }
    }
    int16_t temperature = temp_3h.Data(i);
    if (temperature == INT16_MIN) {
      sprintf(temperature_str, "---");
    } else {
      dtostrf(temperature / 100.0, 3, 1, temperature_str);
    }
    sprintf(buffer, "-%02d: %s ~ %s @ %sC", -hours, pressure_str, delta_str,
            temperature_str);
    DisplayLine(buffer, 24, 16);
    hours += kPeriodHours;
    last_pressure = pressure;
  }

  current_line += 2;
  dtostrf((float)pressure_3h.SerieMin() / 10.0, 5, 1, pressure_str);
  dtostrf((float)pressure_3h.SerieMax() / 10.0, 5, 1, humidity_str);
  sprintf(buffer, "min=%s / max=%s", pressure_str, humidity_str);
  DisplayLine(buffer, 24, 24);
}

void DisplayInfo(DateTime &local, BaroSample &last) {
  char buffer[56];
  char pressure_str[8];
  char temperature_str[8];
  char humidity_str[8];
  char other_str[8];

  canvas->setFont(&ClearSans_Medium12pt7b);
  current_line = 0;

  DateTime utc = DateTime(last.GetTimestamp());
  sprintf(buffer, "UTC : %04d-%02d-%02d %02d:%02d:%02d | Alt=%dm", utc.year(),
          utc.month(), utc.day(), utc.hour(), utc.minute(), utc.second(),
          altitude);
  DisplayLine(buffer, 15);

  sprintf(buffer, "Local: %04d-%02d-%02d %02d:%02d:%02d | TZ=%+d", local.year(),
          local.month(), local.day(), local.hour(), local.minute(),
          local.second(), timezone);
  DisplayLine(buffer, 22);

  dtostrf(last.PressureMilliBar(), 5, 1, pressure_str);
  dtostrf(last.TemperatureDegCelcius(), 4, 1, temperature_str);
  dtostrf(last.HumidityPercent(), 4, 1, humidity_str);
  sprintf(buffer, "Last: p=%s mb | t=%s C | h=%s %%", pressure_str,
          temperature_str, humidity_str);
  DisplayLine(buffer, 22);

  dtostrf((float)daily_buffer.SerieMin() / 10.0, 5, 1, pressure_str);
  dtostrf((float)weekly_buffer.SerieMin() / 10.0, 5, 1, other_str);
  sprintf(buffer, "Min p: 28h=%smb / 4.7d=%smb", pressure_str,
          other_str);
  DisplayLine(buffer, 26);

  dtostrf((float)daily_buffer.SerieMax() / 10.0, 5, 1, pressure_str);
  dtostrf((float)weekly_buffer.SerieMax() / 10.0, 5, 1, other_str);
  sprintf(buffer, "Max p: 28h=%smb / 4.7d=%smb", pressure_str, other_str);
  DisplayLine(buffer, 22);

#ifdef VMEASURE_WORKS
  if (vbat_mv == Vsaturated) {
    sprintf(buffer, "Vbat > 4600mV");
  } else {
    sprintf(buffer, "Vbat = %lu mV", vbat_mv);
  }
#else
  sprintf(buffer, "Vbat = N/A");
#endif
  DisplayLine(buffer, 26);

  sprintf(buffer, "# samples stored on flash = %lu", samples_on_flash);
  DisplayLine(buffer, 26);

  sprintf(buffer, "Min/Max recorded pressure on flash:");
  DisplayLine(buffer, 22);
  DateTime tlow = DateTime(permanent_samples.min_pressure_.GetTimestamp());
  dtostrf(permanent_samples.min_pressure_.PressureMilliBar(), 5, 1,
          pressure_str);
  sprintf(buffer, "%04d-%02d-%02d %02d:%02d:%02d (UTC) -> %s mb", tlow.year(),
          tlow.month(), tlow.day(), tlow.hour(), tlow.minute(), tlow.second(),
          pressure_str);
  DisplayLine(buffer, 22);
  DateTime thigh = DateTime(permanent_samples.max_pressure_.GetTimestamp());
  dtostrf(permanent_samples.max_pressure_.PressureMilliBar(), 5, 1,
          pressure_str);
  sprintf(buffer, "%04d-%02d-%02d %02d:%02d:%02d (UTC) -> %s mb", thigh.year(),
          thigh.month(), thigh.day(), thigh.hour(), thigh.minute(),
          thigh.second(), pressure_str);
  DisplayLine(buffer, 22);

  uptime_seconds = utc.secondstime() - boot_utc.secondstime();
  TimeSpan up = TimeSpan(uptime_seconds);
  sprintf(buffer, "loop counter=%ld | awake=%lds", loop_counter,
          awake_centiseconds / 100);
  DisplayLine(buffer, 22);
  sprintf(buffer, "uptime: %dd %dh %dm (%lus)", up.days(), up.hours(),
          up.minutes(), uptime_seconds);
  DisplayLine(buffer, 22);
  sprintf(buffer, "build: %s (%s)", DIGIBARO_VERSION, __DATE__);
  DisplayLine(buffer, 22);
}

void DisplayHeader(DateTime &local, BaroSample &sample) {
  char buffer[16];
  canvas->setFont(&ClearSans_Medium32pt7b);
  int16_t u, l, x, y;
  uint16_t w, h;

  sprintf(buffer, "%02d:%02d", local.hour(), local.minute());
  canvas->getTextBounds(buffer, 0, 44, &u, &l, &w, &h);
  x = w;
  y = h;
  canvas->setCursor(0, y);
  canvas->print(buffer);

  dtostrf(sample.PressureMilliBar(), 5, 1, buffer);
  canvas->getTextBounds(buffer, 0, y, &u, &l, &w, &h);
  canvas->setCursor(390 - w, y);
  canvas->print(buffer);

  canvas->setFont(&ClearSans_Medium12pt7b);
  sprintf(buffer, "TZ=%+d", timezone);
  canvas->setCursor(x + 16, 16);
  canvas->print(buffer);

  sprintf(buffer, "%dm", altitude);
  canvas->setCursor(x + 16, y);
  canvas->print(buffer);
}

void Display(DateTime &local, BaroSample &sample, uint8_t mode) {
  uint32_t count;

  // Display was powered OFF: need to wake up (with reset)
  if (ep42_display.Init() != 0) {
    flash_debug.Message(FlashDebug::STEP, DEVICE_EPD42_ID, -1);
    while (1)
      ;
  }

  ep42_display.ConfigAndSendOldBuffer(canvas->getBuffer());

  canvas->fillScreen(1);
  DEBUG("display mode", mode);

  switch (mode) {
    case DisplayMode::INFO:
      DisplayInfo(local, sample);
      break;
    case DisplayMode::STATS:
      DisplayStats(local, sample);
      break;
    case DisplayMode::DAILY:
      count = daily_buffer.Fill(rotating_samples, sample.GetTimestamp());
      if (count > 0) {
        daily_buffer.Draw(*canvas, 1, 0);
      }
      DisplayHeader(local, sample);
      break;
    case DisplayMode::WEEKLY:
      count = weekly_buffer.Fill(rotating_samples, sample.GetTimestamp());
      if (count > 0) {
        weekly_buffer.Draw(*canvas, 1, 0);
      }
      DisplayHeader(local, sample);
      break;
    default:
      break;
  }

  ep42_display.SendNewBufferAndRefresh(canvas->getBuffer());
  ep42_display.Sleep();
}

void loop() {
  static uint32_t after_awake = millis();
  wdt_reset();  // Tell the watchdog timer everything is fine
  loop_counter++;

  // Enable power to the external RTC and display
  digitalWrite(kRtcPowerPin, HIGH);
  delay(50);

  DateTime utc = ds3231_rtc.now();
  SyncOnboardRTC(utc);
  DateTime local = utc.getLocalTime(timezone);

  // Get display mode from rocker switches state
  uint8_t wake_switch_state = GetSwitchesState();
  ConfigureSettingsFromDip();
  BaroSample last_measurement = CollectSample(utc, local);
  vbat_mv = MeasureVbat();

  if (!timer_wakeup || utc.minute() % DAILY_PERIOD_MINUTE == 0) {
    // Update display only to the period in minute defined above
    // or if awakened by external switch input.
    Display(local, last_measurement, wake_switch_state);
  }

#ifndef KEEP_AWAKE
  uint8_t new_switch_state = GetSwitchesState();
  if (new_switch_state == wake_switch_state) {
    // Only go in standby mode if switches were not modified
    ConfigureForSleep();
    awake_centiseconds += ((millis() - after_awake)) / 10;

    // Go in standby mode for 1 minute!
    // flash_debug.Message(FlashDebug::STANDBY, 1, loop_counter);
    onboard_rtc.standbyMode();

    // now we are awake again! --> detach the interrupts
    onboard_rtc.detachInterrupt();
    for (size_t p = 0; p < 2; p++) {
      detachInterrupt(kSwitchesPin[p]);
    }
    after_awake = millis();
    digitalWrite(LED_BUILTIN, HIGH);
    // flash_debug.Message(FlashDebug::WAKEUP, 1, awake_centiseconds /
    // (100*60));

    CheckAndWaitForSerial();
  }
#else
  delay(10 * 1000);
#endif
}

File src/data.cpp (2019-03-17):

#include "data.h"

#include <SPIMemory.h>

FastCRC8 Int24Crc8::crc8_;

#define Serial SERIAL_PORT_USBVIRTUAL

RobustFlashIndexes::RobustFlashIndexes(uint32_t sector_start,
                                       uint32_t total_sectors)
    : sector_start_(sector_start) {
  if (total_sectors % 2 != 0) {
    total_sectors--;
  }
  //   Serial.println("RobustFlashIndexes constructor");
  nb_sectors_ = total_sectors / 2;
  nb_indexes_ = nb_sectors_ * kSectorLength / 4;
  indexes_start_[0] = sector_start * kSectorLength;
  indexes_start_[1] = indexes_start_[0] + nb_sectors_ * kSectorLength;
}

void RobustFlashIndexes::begin(SPIFlash *flash) {
  flash_ = flash;
  Serial.println("---- BEGIN ---- RobustFlashIndexes::begin()");
  Serial.print("nb_sector:          ");
  Serial.println(nb_sectors_);
  Serial.print("nb_indexes:         ");
  Serial.println(nb_indexes_);
  Serial.print("indexes_start[0]:   ");
  Serial.println(indexes_start_[0]);
  Serial.print("indexes_start[1]:   ");
  Serial.println(indexes_start_[1]);
  current_index_ = RetrieveLastIndex();
  current_counter_ = GetCurrentCounter();
  Serial.print("current index = ");
  Serial.println(current_index_);
  Serial.println("---- END ---- RobustFlashIndexes::begin()");
}

uint32_t RobustFlashIndexes::RetrieveLastIndex() {
  uint32_t first[2];
  Serial.println("RobustFlashIndexes::RetrieveLastIndex()");
  for (int i = 0; i < 2; i++) {
    first[i] = flash_->readLong(indexes_start_[i]);
  }
//   Serial.print("first[0] = ");
//   Serial.println(first[0], HEX);
//   Serial.print("first[0] = ");
//   Serial.println(first[0], HEX);
  // Check if memory was correctly initialized
  if (first[0] == 0xFFFFFFFF || first[1] == 0xFFFFFFFF) {
    if (first[0] == first[1]) {
      Serial.println("Indexes not initialized.");
    } else {
      Serial.println("Indexes not correctly initialized!");
    }
    InitializeMemory();
    return 0;
  }

  Serial.println("start searching for last index...");
  // Search for the last index
  uint32_t addr[2] = {indexes_start_[0], indexes_start_[1]};
  for (uint32_t i = 0; i < nb_indexes_ - 1; i++) {
    addr[0] += 4;
    addr[1] += 4;
    // Serial.print("checking index ");
    // Serial.print(i, DEC);
    // Serial.print(" at addr1=");
    // Serial.print(addr[0]);
    // Serial.print(" / addr2=");
    // Serial.println(addr[1]);
    uint32_t first = flash_->readLong(addr[0]);
    uint32_t second = flash_->readLong(addr[1]);
    if (first == 0xFFFFFFFF || second == 0xFFFFFFFF) {
      Serial.print("encountered unwritten memory for index ");
      Serial.print(i + 1);
      Serial.print(" at memory ");
      Serial.print(addr[0]);
      Serial.print(" / ");
      Serial.println(addr[1]);
      if ( first != second ) {
          Serial.println("Probable memory corruption: index termination do not match");
      }
      return i;
    }
  }
  return kInvalidInt24;
}

uint32_t RobustFlashIndexes::Increment() {
  //   Serial.print("current counter = ");
  //   Serial.println(current_counter_);
  current_counter_++;
  current_index_++;
  //   Serial.print("next index = ");
  //   Serial.println(current_index_);
  if (current_index_ >= nb_indexes_ ) {
    current_index_ = 0;
  }
  uint32_t offset = current_index_ * sizeof(uint32_t);
  uint32_t addr[2] = {indexes_start_[0] + offset, indexes_start_[1] + offset};

  if (current_index_ % (kSectorLength/sizeof(uint32_t)) == 0) {
    // entering a new sector!
    Serial.print("Entering new sector for index = ");
    Serial.println(current_index_);
    uint32_t code[2];
    code[0] = flash_->readLong(addr[0]);
    code[1] = flash_->readLong(addr[1]);
    if (code[0] != 0xFFFFFFFF || code[1] != 0xFFFFFFFF) {
      if (code[0] != code[1]) {
        Serial.println("WARNING: sectors not in sync!");
      }
      Serial.print("Erasing sectors starting at: ");
      Serial.print(addr[0]);
      Serial.print(" / ");
      Serial.println(addr[1]);
      flash_->eraseSector(addr[0]);
      flash_->eraseSector(addr[1]);
    }
  }

  DoubleWriteInt24(current_counter_, addr[0], addr[1]);
  return current_counter_;
}

uint32_t RobustFlashIndexes::GetCurrentCounter() {
  uint32_t offset = current_index_ * sizeof(uint32_t);
  return ReadCheckInt24(indexes_start_[0] + offset, indexes_start_[1] + offset);
}

bool RobustFlashIndexes::InitializeMemory() {
  Serial.println("RobustFlashIndexes::InitializeMemory()");
  uint32_t addr[2] = {indexes_start_[0], indexes_start_[1]};
  for (uint32_t i = 0; i < nb_sectors_; i++) {
    if (!flash_->eraseSector(addr[0])) {
      Serial.print("Error erasing sector starting at ");
      Serial.println(addr[0]);
    }
    if (!flash_->eraseSector(addr[1])) {
      Serial.print("Error erasing sector starting at ");
      Serial.println(addr[1]);
    }
    addr[0] += kSectorLength;
    addr[1] += kSectorLength;
  }
  current_index_ = 0;
  current_counter_ = 0;
  return DoubleWriteInt24(current_counter_, indexes_start_[0], indexes_start_[1]);
}

uint32_t RobustFlashIndexes::ReadCheckInt24(uint32_t addr1, uint32_t addr2) {
  uint32_t first = flash_->readLong(addr1, false);
  uint32_t second = flash_->readLong(addr2, false);
  bool first_crc = Int24Crc8::Check(first);
  bool second_crc = Int24Crc8::Check(second);
  if (!first_crc && !second_crc) {
    Serial.println("Both indexes CRC are wrong (cannot thrust either value)!");
    return kInvalidInt24;
  }
  if (!first_crc) {
    Serial.println("CRC for first index is wrong!");
    return Int24Crc8::Data(second);
  }
  if (!second_crc) {
    Serial.println("CRC for second index is wrong!");
    return Int24Crc8::Data(first);
  }
  if (first != second) {
    Serial.println(
        "Double double fault (CRC are correct but number do not match)!");
    return kInvalidInt24;
  }
  return Int24Crc8::Data(first);
}

bool RobustFlashIndexes::DoubleWriteInt24(uint32_t value, uint32_t addr1,
                                          uint32_t addr2) {
  uint32_t code = Int24Crc8::Create(value);
  //   Serial.print("Double write(");
  //   Serial.print(value);
  //   Serial.print(") : addr1=");
  //   Serial.print(addr1);
  //   Serial.print(" / addr2=");
  //   Serial.println(addr2);
  if (flash_->writeLong(addr1, code, true)) {
    if (flash_->writeLong(addr2, code, true)) {
      return true;
    }
  }
  return false;
}

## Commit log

2019-03-17 started constructing a sample data structure (untested)
2019-03-19 starting testing sample packing... bug for negative numbers
    [main.cpp]
2019-03-21 fixed negative number packing on 14 bits for good
    [main.cpp]
2019-03-23 added the correct version of the driver!
2019-03-31 added sample collector and reader test programs
2019-04-14 added some collected data and associated plot
    [samples_raw.csv, samples_with_header.csv]
2019-04-17 added utility to support writing/reading time serie samples
2019-04-17 use correctly indexed sample (starting at 0)
2019-04-19 added new class to support rotating samples
2019-04-21 added a period between hourly samples and a default constructor with and invalid sample
2019-04-21 removed some debugging print statements
2019-04-21 added pretty print method
2019-04-21 executable to wipe out the permanent samples
2019-04-23 correct extra space in build command
    [main.cpp]
2019-04-23 SAMD21 sleep test functional with I2C and SPI devices (25uA)
2019-04-28 printout management
2019-04-28 simple sample generator added for testing
2019-04-28 started program to read samples in the ring buffer
2019-04-29 Added WaveShare code. See note below.
    Purpose: avoid to have a submodule pulling the full WaveShare repo (which did not exist
    when the project was started anyway). The code here is ONLY for the 4.2in (400x300)
    B&W (revision A) of the e-Paper display, with ONLY the Arduino code (no demo).
    Source: https://www.waveshare.com/wiki/4.2inch_e-Paper_Module
    License: WaveShare custom (see any header file)
    Current Git repo: https://github.com/waveshare/e-Paper/tree/master/4.2inch_e-paper_code
2019-04-29 removes 100 lines (manually) to creates "holes" in the dataset
2019-04-29 added class to manage samples from flash into RAM for fast display
2019-05-06 removed some printout
2019-05-12 added debug print functions
2019-05-12 removed that memory map switch
2019-05-12 performance for display sample working again
2019-05-12 better implementation that averages samples (if available) when filling the buffer
2019-05-13 Added graphing to display samples
2019-05-20 trying to add an external interrupt (not working yet)
    [external_interrupt.cpp, sleep_test.cpp]
2019-05-21 external switch wake the board up correctly from deepsleep :-)
    [external_interrupt.cpp]
2019-05-21 disabled flash to save more, added circuit doc
2019-05-21 added new test for low power dip switch
2019-05-22 fixed switch description
2019-05-27 added current Eagle design
    [battery_holder.dxf, digibaro_v2.brd, digibaro_v2.sch]
2019-05-30 fixed schematic, corrected footprint (switch + rocket scream) and improved layout
    [digibaro_v2.brd, digibaro_v2.sch]
2019-06-03 Minimize power and still manage correctly buses
    Consumption in standby: 22uA (4.5V)
    Works correctly for all conditions:
    - bare board (nor external RTC), on board flash (SPI)
    - no display but RTC in I2C
    - e-Paper display on SPI + RTC on I2C
    [sleep_test.cpp]
2019-06-04 skeleton of app working correctly with standby
    [devices.cpp, digibaro.h, main.cpp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]
2019-06-05 added the external switches wakup
2019-06-24 scale the Y axis for series with no variation (or quasi empty)
2019-06-25 added DIP switch support for settings
2019-06-25 fixed DST and reverse switch
    [main.cpp]
2019-06-26 restore IfSleep to minimize current draw in standby
2019-06-27 fixed switch mode and tuned periods
    [devices.cpp, digibaro.h, main.cpp]
2019-07-08 declare the maximum allowed pressure
2019-07-08 do not mess up with utc (need to fix RTClib\!)
    [main.cpp]
2019-07-16 use proper case for include
2019-09-14 added brochure files
    [digibaro v52.dwg, icons.dwg]
2019-09-14 Updated with current status

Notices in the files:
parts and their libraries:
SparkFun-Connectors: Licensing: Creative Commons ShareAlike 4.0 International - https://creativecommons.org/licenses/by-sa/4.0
